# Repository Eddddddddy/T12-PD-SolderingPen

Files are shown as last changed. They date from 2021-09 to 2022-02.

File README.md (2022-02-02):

# T12-PD-SolderingPen

[Video introduction]<https://www.bilibili.com/video/BV1734y1D7u2>

使用atmega328p作为主控芯片，128x64 OLED屏幕，内置陀螺仪和蜂鸣器。能够读取控制部分电路温度和输入电压，主控电压，主控温度。具备自动启停的功能。

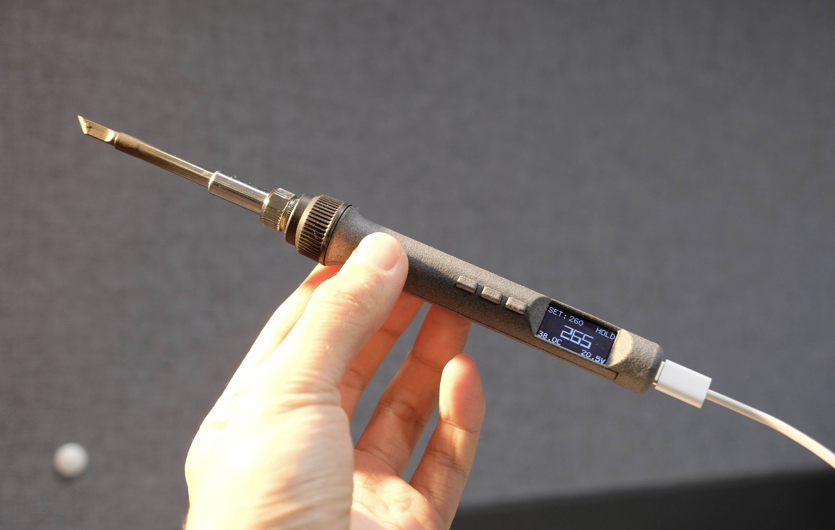
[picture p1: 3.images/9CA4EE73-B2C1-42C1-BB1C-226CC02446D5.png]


可以保存多组不同的烙铁头信息。烙铁主控部分代码基于<https://github.com/wagiminator/ATmega-Soldering-Station>.在屏幕驱动、按键驱动、休眠检测、陀螺仪和内部温度检测等方面做出调整与改进。

- 休眠功能通过陀螺仪进行检测，可以设置休眠时间和灵敏度。默认的阈值较灵敏，轻微的晃动就会唤醒。休眠功能可以关闭，将灵敏度的阈值设置为0即可。
- 蜂鸣器可以选择开启或关闭
- 加热方式可以选择直接加热或PID调节，但PID参数尚未调整，可在源代码中自行调整。
- 烙铁温度可以在设置中校准

## 制作信息

- 手柄部分请使用1.6mm双层板打样，主控部分请使用0.8mm四层板。

- 屏幕较为特殊，为0.96寸64x128分辨率sh1107驱动OLED屏幕，0.3mm脚距插接13pin接口。

- FS312协议芯片请使用H版，以支持20v电压。

- 建议开一张钢片用锡膏焊接，大大降低难度。

- 焊接完成之后需要飞线到预留的焊盘，进行程序烧录。

## 注意事项

- 支架与主控需共地
- 如果主控不是原厂的芯片，在information页面的主控温度可能会不正常。但不影响使用
- 建议通过<https://github.com/carlosefr/atmega>页面的步骤对芯片进行烧写。该开发板包将会释放BootLoader占用的flash空间，在下述“烧录引导程序”步骤中将熔丝位修改正确。
- 简单来说，安装上面连接中的开发板到Arduino IDE，并在开发板中选中"ATmega328/328p" - "ATmega328p" - "16 MHz" - 编程器："Arduino as ISP"
- 准备一个Arduino UNO，烧写Arduino示例程序中的ArduinoISP。将Arduino UNO的相应管脚与主控板上相应的飞线焊盘连接。在Arduino IDE中点击“烧录引导程序”，完成之后再点击“使用编程器上传”，即可完成烧录工作。

更多信息稍后更新。

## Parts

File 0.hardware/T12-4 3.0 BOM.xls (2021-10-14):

Comment | Description | Designator | Footprint | Quantity
100nF 10% 50V | 贴片电容 | C1, C3, C10, C17, C18 | 0603_C | 5
1uF 10% 50V | 贴片电容 | C2, C11, C13 | 0603_C | 3
2.2nF 10% 50V | 贴片电容 | C5 | 0603_C | 1
10uF 10% 50V | 贴片电容 | C6, C15, C16, C20 | 0603_C | 4
4.7uF 10% 50V | 贴片电容 | C7, C19 | 0603_C | 2
33pF 5% 50V | 贴片电容 | C9 | 0603_C | 1
10pF 5% 50V | 贴片电容 | C14 | 0603_C | 1
B5819W SL | 肖特基二极管 | D1, D3, D4 | SOD-123 | 3
1N4148WS T4 | 二极管 | D2 | SOD-323 | 1
22uh | 电感 | H1 | NR3015 | 1
OPA333AIDCKR |  | Designator47 | SC70-5 | 1
FXMAR2102UMX |  | Designator48 | UMLP-8 | 1
47uh |  | H2 | NR3015 | 1
TYPE-C-31-M-12 | USB Connectors 24 Receptacle 1 8.94*7.3mm RoHS | J | TYPE-C-31-M-12 | 1
AO4485 | Transistor: P-MOSFET; unipolar; -40V; -8A; 1.1W; SO8 | Q1 | SOIC127P600X175-8N | 1
SS8050 Y1 | 三极管 | Q2 | SOT-23(SOT-23-3) | 1
10KΩ ±1% | 贴片电阻 | R1, R6, R11, R12, R14, R15, R16 | 0603_R | 7
200KΩ ±1% | 贴片电阻 | R4 | 0603_R | 1
1KΩ ±1% | 贴片电阻 | R5 | 0603_R | 1
23.7KΩ ±1% | 贴片电阻 | R7 | 0603_R | 1
124KΩ ±1% | 贴片电阻 | R8 | 0603_R | 1
22KΩ ±1% | 贴片电阻 | R9 | 0603_R | 1
47KΩ ±1% | 贴片电阻 | R10 | 0603_R | 1
180KΩ ±1% | 贴片电阻 | R13 | 0603_R | 1
4.7KΩ ±1% | 贴片电阻 | R17, R18, R21, R22, R25, R27 | 0603_R | 6
100KΩ ±1% | 贴片电阻 | R23 | 0603_R | 1
560KΩ ±1% | 贴片电阻 | R26, R24 | 0603_R | 1
MP2451DT-LF-Z |  | U1 | SOT-23-6_L2.9-W1.6-P0.95-LS2.8-BR | 1
FS312 |  | U4 | FS312 | 1
LIS2DW12TR | Mems Digital Output Motion Sensor | U5 | LGA12R50P4X4_200X200X70 | 1
MCU-ATMEGA328P-AU(TQFP32) | 310010049 | U6 | TQFP32-0.8-7X7MM | 1
PMIC-LDO-XC6206P332MR-G(SOT23) | 310030099 | U7 | SOT-23 | 1
SH1107 |  | U8 | FH35C-13S | 1
TPS61040DBVRG4 | DC-DC芯片 | U9 | SOT-23-5 | 1
CSTCE16M0V51Z-R0 | 16MHz Ceramic Resonator Built in Capacitor 15pF +/- 0.2% -40C - 125C Surface Mount | Y1 | OSC_CSTCE16M0V51Z-R0 | 1
DET402 | 蜂鸣器 |  | SMD402
2*4*3.5MM 侧贴 | 贴片开关
1N4148 | 二极管 |  | SOD-523
S8050 J3Y | 三极管 |  | SOT-23
10KΩ ±1% | 贴片电阻 |  | 0603_R

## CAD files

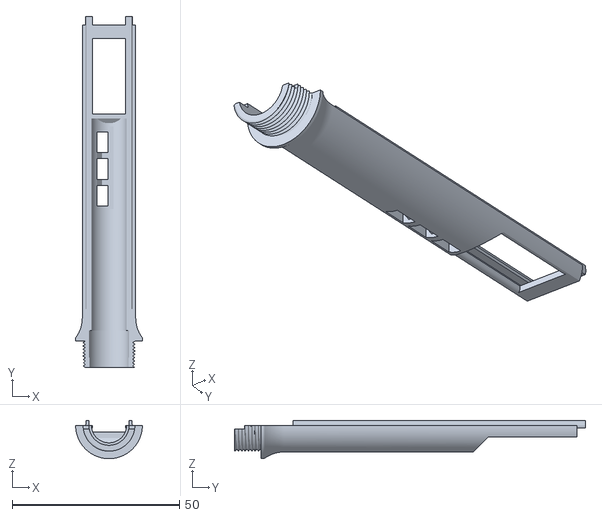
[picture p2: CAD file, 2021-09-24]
2.3D STL/part1.STL
20.0 x 105.0 x 11.5

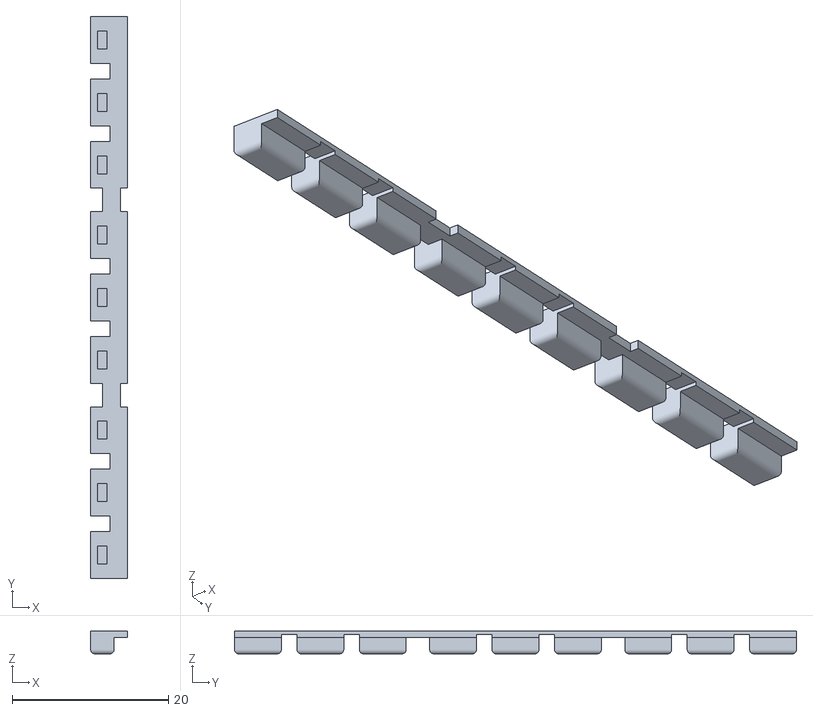
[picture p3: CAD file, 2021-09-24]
2.3D STL/buttons.STL
4.70 x 72.0 x 2.92

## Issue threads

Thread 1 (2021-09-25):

关于动画...

Challenger-0, 2021-09-25:
B站来的
您的项目应该是用Arduino开发的，用u8g2实现显示的吧
虽然我并不专业，但自认为有信心和能力帮您完成动画的部分
QQ1677712032

Eddddddddy, 2021-09-25:
来了！

hqs1, 2021-09-29:
LVGL yyds,但是328P的资源有点小，可能上ESP32这种主控比较舒服点

Eddddddddy, 2021-09-29:
> LVGL yyds,但是328P的资源有点小，可能上ESP32这种主控比较舒服点

对，我是真的后悔用328p，资源太少了，还得单独给一个供电

Closed 2021-10-03.

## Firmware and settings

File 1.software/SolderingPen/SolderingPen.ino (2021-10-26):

// SolderingPen
//
// ATmega328-controlled Soldering Pen for Hakko T12 Tips.
//
// This version of the code implements:
// - Temperature measurement of the tip
// - Direct or PID control of the heater
// - Temperature control via buttons
// - Boost mode by short pressing first button
// - Setup menu by long pressing first button
// - Handle movement detection by gyroscope
// - Iron unconnected detection (by idenfying invalid temperature readings)
// - Time driven sleep/power off mode if iron is unused (movement detection)
// - Measurement of input voltage, Vcc and ATmega's internal temperature
// - Information display on OLED
// - Buzzer
// - Calibrating and managing different soldering tips
// - Storing user settings into the EEPROM
// - Tip change detection
// - Can be used with either N or P channel mosfets
//
// Power supply should be in the range of 6V to 20V. PD, QC and other
// rapid-charging protocols.
//
// For calibration you need a soldering iron tips thermometer. For best results
// wait at least three minutes after switching on the soldering station before
// you start the calibration process.
//
// Controller:  ATmega328p
// Core:        Barebones ATmega (https://github.com/carlosefr/atmega)
// Clockspeed:  16 MHz external
//
// It is recommended not to use a bootloader!
//
// Thank you for the code contributions:
// - John Glavinos, https://youtu.be/4YDcWfOQmz4
// - createskyblue, https://github.com/createskyblue
// - TaaraLabs, https://github.com/TaaraLabs
// - wagiminator, https://github.com/wagiminator



// Libraries
#include <U8g2lib.h>             // https://github.com/olikraus/u8g2

#ifdef U8X8_HAVE_HW_SPI
#include <SPI.h>
#endif
#ifdef U8X8_HAVE_HW_I2C
#include <Wire.h>
#endif

#include <PID_v1.h>             // https://github.com/wagiminator/ATmega-Soldering-Station/blob/master/software/libraries/Arduino-PID-Library.zip
// (old cpp version of https://github.com/mblythe86/C-PID-Library/tree/master/PID_v1)
#include <EEPROM.h>             // for storing user settings into EEPROM
#include <avr/sleep.h>          // for sleeping during ADC sampling

#include "LIS2DW12Sensor.h"

// Firmware version
#define VERSION       "v1.5"

// Type of MOSFET
#define P_MOSFET                // P_MOSFET or N_MOSFET

// Type of OLED Controller
#define SH1107                 // SH1107
typedef u8g2_uint_t u8g_uint_t;

// Type of rotary encoder
#define ROTARY_TYPE   0         // 0: 2 increments/step; 1: 4 increments/step (default)
#define BUTTON_DELAY  5

// Pins
#define SENSOR_PIN    A0        // tip temperature sense
#define VIN_PIN       A1        // input voltage sense
#define BUZZER_PIN     5        // buzzer
#define BUTTON_PIN     6        // rotary encoder switch
#define BUTTON_P_PIN   7        // rotary encoder 1
#define BUTTON_N_PIN   8        // rotary encoder 2
#define CONTROL_PIN    9        // heater MOSFET PWM control
#define SWITCH_PIN    10        // handle vibration switch

// Default temperature control values (recommended soldering temperature: 300-380°C)
#define TEMP_MIN      150       // min selectable temperature
#define TEMP_MAX      400       // max selectable temperature
#define TEMP_DEFAULT  320       // default start setpoint
#define TEMP_SLEEP    150       // temperature in sleep mode
#define TEMP_BOOST     50       // temperature increase in boost mode
#define TEMP_STEP      10       // rotary encoder temp change steps

// Default tip temperature calibration values
#define TEMP200       216       // temperature at ADC = 200
#define TEMP280       308       // temperature at ADC = 280
#define TEMP360       390       // temperature at ADC = 360
#define TEMPCHP       30        // chip temperature while calibration
#define TIPMAX        8         // max number of tips
#define TIPNAMELENGTH 6         // max length of tip names (including termination)
#define TIPNAME       "BC1.5"   // default tip name

// Default timer values (0 = disabled)
#define TIME2SLEEP    30        // time to enter sleep mode in minutes
#define TIME2OFF       5        // time to shut off heater in minutes
#define TIMEOFBOOST   40        // time to stay in boost mode in seconds
#define LISTHRESHOLD  15        // LIS sensor threshold

// Control values
#define TIME2SETTLE   950       // time in microseconds to allow OpAmp output to settle
#define SMOOTHIE      0.05      // OpAmp output smooth factor (1=no smoothing; 0.05 default)
#define PID_ENABLE    false     // enable PID control
#define BEEP_ENABLE   true      // enable/disable buzzer
#define MAINSCREEN    1         // type of main screen (0: big numbers; 1: more infos)

// EEPROM identifier
#define EEPROM_IDENT  0xE76C   // to identify if EEPROM was written by this program

// MOSFET control definitions
#if defined (P_MOSFET)         // P-Channel MOSFET
#define HEATER_ON   255
#define HEATER_OFF  0
#define HEATER_PWM  255 - Output
#elif defined (N_MOSFET)       // N-Channel MOSFET
#define HEATER_ON   0
#define HEATER_OFF  255
#define HEATER_PWM  Output
#else
#error Wrong MOSFET type!
#endif

// Define the aggressive and conservative PID tuning parameters
double aggKp = 11, aggKi = 0.5, aggKd = 1;
double consKp = 11, consKi = 3, consKd = 5;

// Default values that can be changed by the user and stored in the EEPROM
uint16_t  DefaultTemp   = TEMP_DEFAULT;
uint16_t  SleepTemp     = TEMP_SLEEP;
uint8_t   BoostTemp     = TEMP_BOOST;
uint8_t   time2sleep    = TIME2SLEEP;
uint8_t   time2off      = TIME2OFF;
uint8_t   timeOfBoost   = TIMEOFBOOST;
uint8_t   MainScrType   = MAINSCREEN;
bool      PIDenable     = PID_ENABLE;
bool      beepEnable    = BEEP_ENABLE;
uint8_t   LISthreshold  = LISTHRESHOLD;

// Default values for tips
uint16_t  CalTemp[TIPMAX][4] = {TEMP200, TEMP280, TEMP360, TEMPCHP};
char      TipName[TIPMAX][TIPNAMELENGTH] = {TIPNAME};
uint8_t   CurrentTip   = 0;
uint8_t   NumberOfTips = 1;

// Menu items
const char *SetupItems[]       = { "Setup Menu", "Tip Settings", "Temp Settings",
                                   "Timer Settings", "Control Type", "Main Screen",
                                   "Buzzer", "Information", "Return"
                                 };
const char *TipItems[]         = { "Tip:", "Change Tip", "Calibrate Tip",
                                   "Rename Tip", "Delete Tip", "Add new Tip", "Return"
                                 };
const char *TempItems[]        = { "Temp Settings", "Default Temp", "Sleep Temp",
                                   "Boost Temp", "Return"
                                 };
const char *TimerItems[]       = { "Timer Settings", "Sleep Timer", "Off Timer",
                                   "Boost Timer", "IMU Threshold", "Return"
                                 };
const char *ControlTypeItems[]  = { "Control Type", "Direct", "PID" };
const char *MainScreenItems[]   = { "Main Screen", "Big Numbers", "More Infos" };
const char *StoreItems[]        = { "Store Settings ?", "No", "Yes" };
const char *SureItems[]         = { "Are you sure ?", "No", "Yes" };
const char *BuzzerItems[]       = { "Buzzer", "Disable", "Enable" };
const char *DefaultTempItems[]  = { "Default Temp", "deg C" };
const char *SleepTempItems[]    = { "Sleep Temp", "deg C" };
const char *BoostTempItems[]    = { "Boost Temp", "deg C" };
const char *SleepTimerItems[]   = { "Sleep Timer", "Seconds" };
const char *LISthresholdItems[] = { "IMU Threshold", "mg" };
const char *OffTimerItems[]     = { "Off Timer", "Minutes" };
const char *BoostTimerItems[]   = { "Boost Timer", "Seconds" };
const char *DeleteMessage[]     = { "Warning", "You cannot", "delete your", "last tip!" };
const char *MaxTipMessage[]     = { "Warning", "You reached", "maximum number", "of tips!" };

// Variables for pin change interrupt
volatile uint8_t  a0, b0, c0, d0;
volatile bool     ab0;
volatile int      count, countMin, countMax, countStep;
volatile bool     handleMoved;

// Variables for temperature control
uint16_t  SetTemp, ShowTemp, gap, Step;
double    Input, Output, Setpoint, RawTemp, CurrentTemp, ChipTemp;

// Variables for voltage readings
uint16_t  Vcc, Vin;

// State variables
bool      inSleepMode = false;
bool      inOffMode   = false;
bool      inBoostMode = false;
bool      inCalibMode = false;
bool      isWorky     = true;
bool      beepIfWorky = true;
bool      TipIsPresent = true;

// Timing variables
uint32_t  sleepmillis;
uint32_t  boostmillis;
uint32_t  buttonmillis;
uint8_t   goneMinutes;
uint8_t   goneSeconds;
uint8_t   SensorCounter = 255;

// Specify variable pointers and initial PID tuning parameters
PID ctrl(&Input, &Output, &Setpoint, aggKp, aggKi, aggKd, REVERSE);

// Setup u8g object depending on OLED controller
#if defined (SSD1306)
U8GLIB_SSD1306_128X64 u8g(U8G_I2C_OPT_DEV_0 | U8G_I2C_OPT_NO_ACK | U8G_I2C_OPT_FAST);
#elif defined (SH1106)
U8GLIB_SH1106_128X64 u8g(U8G_I2C_OPT_FAST | U8G_I2C_OPT_NO_ACK);
#elif defined (SH1107)
U8G2_SH1107_64X128_1_HW_I2C u8g(U8G2_R1, A3);
#else
#error Wrong OLED controller type!
#endif

// Buffer for drawStr
char F_Buffer[20];

// LIS2DW12Sensor
LIS2DW12Sensor Accelero(&Wire, LIS2DW12_I2C_ADD_L);
LIS2DW12_Event_Status_t state;
float lastLISTmp = 0;
float newLISTmp = 0;
uint8_t LISTmpTime = 0;


void setup() {
  // set the pin modes
  pinMode(SENSOR_PIN,   INPUT);
  pinMode(VIN_PIN,      INPUT);
  pinMode(BUZZER_PIN,   OUTPUT);
  pinMode(CONTROL_PIN,  OUTPUT);
  pinMode(BUTTON_P_PIN, INPUT_PULLUP);
  pinMode(BUTTON_N_PIN, INPUT_PULLUP);
  pinMode(BUTTON_PIN,   INPUT_PULLUP);
  pinMode(SWITCH_PIN,   INPUT_PULLUP);

  analogWrite(CONTROL_PIN, HEATER_OFF); // this shuts off the heater
  digitalWrite(BUZZER_PIN, LOW);        // must be LOW when buzzer not in use

  // setup ADC
  ADCSRA |= bit (ADPS0) | bit (ADPS1) | bit (ADPS2);  // set ADC prescaler to 128
  ADCSRA |= bit (ADIE);                 // enable ADC interrupt
  interrupts ();                        // enable global interrupts

  // // setup pin change interrupt for rotary encoder
  // PCMSK0 = bit (PCINT0);                // Configure pin change interrupt on Pin8
  // PCICR  = bit (PCIE0);                 // Enable pin change interrupt
  // PCIFR  = bit (PCIF0);                 // Clear interrupt flag

  // setup LIS
  Wire.begin();
  Accelero.begin();
  Accelero.Enable_X();
  Accelero.WriteReg(LIS2DW12_CTRL6, 0x04);
  Accelero.WriteReg(LIS2DW12_CTRL1, 0x17);
  Accelero.Set_FIFO_Mode(LIS2DW12_STREAM_MODE);

  // prepare and start OLED
  u8g.begin();
  //  if      ( u8g.getMode() == U8G_MODE_R3G3B2 )   u8g.setColorIndex(255);
  //  else if ( u8g.getMode() == U8G_MODE_GRAY2BIT ) u8g.setColorIndex(3);
  //  else if ( u8g.getMode() == U8G_MODE_BW )       u8g.setColorIndex(1);
  //  else if ( u8g.getMode() == U8G_MODE_HICOLOR )  u8g.setHiColorByRGB(255,255,255);

  // get default values from EEPROM
  getEEPROM();

  // read supply voltages in mV
  delay(100);
  Vcc = getVCC(); Vin = getVIN();

  // read and set current iron temperature
  SetTemp  = DefaultTemp;
  RawTemp  = denoiseAnalog(SENSOR_PIN);
  ChipTemp = getChipTemp();
  calculateTemp();

  // turn on heater if iron temperature is well below setpoint
  if ((CurrentTemp + 20) < DefaultTemp) analogWrite(CONTROL_PIN, HEATER_ON);

  // set PID output range and start the PID
  ctrl.SetOutputLimits(0, 255);
  ctrl.SetMode(AUTOMATIC);

  // set initial rotary encoder values
  //a0 = PINB & 1; b0 = PIND >> 7 & 1; ab0 = (a0 == b0);
  a0 = 0;
  b0 = 0;
  setRotary(TEMP_MIN, TEMP_MAX, TEMP_STEP, DefaultTemp);

  // reset sleep timer
  sleepmillis = millis();

  lastLISTmp = getLISTemp();

  // long beep for setup completion
  beep(); beep();
}


void loop() {
  ROTARYCheck();      // check rotary encoder (temp/boost setting, enter setup menu)
  SLEEPCheck();       // check and activate/deactivate sleep modes
  SENSORCheck();      // reads temperature and vibration switch of the iron
  Thermostat();       // heater control
  MainScreen();       // updates the main page on the OLED
}




// check rotary encoder; set temperature, toggle boost mode, enter setup menu accordingly
void ROTARYCheck() {
  // set working temperature according to rotary encoder value
  SetTemp = getRotary();

  // check rotary encoder switch
  uint8_t c = digitalRead(BUTTON_PIN);
  if ( !c && c0 ) {
    beep();
    buttonmillis = millis();
    while ( (!digitalRead(BUTTON_PIN)) && ((millis() - buttonmillis) < 500) );
    if ((millis() - buttonmillis) >= 500) SetupScreen();
    else {
      inBoostMode = !inBoostMode;
      if (inBoostMode) boostmillis = millis();
      handleMoved = true;
    }
  }
  c0 = c;

  // check timer when in boost mode
  if (inBoostMode && timeOfBoost) {
    goneSeconds = (millis() - boostmillis) / 1000;
    if (goneSeconds >= timeOfBoost) {
      inBoostMode = false;              // stop boost mode
      beep();                           // beep if boost mode is over
      beepIfWorky = true;               // beep again when working temperature is reached
    }
  }
}


// check and activate/deactivate sleep modes
void SLEEPCheck() {
  if (handleMoved) {                    // if handle was moved
    if (inSleepMode) {                  // in sleep or off mode?
      if ((CurrentTemp + 20) < SetTemp) // if temp is well below setpoint
        analogWrite(CONTROL_PIN, HEATER_ON);    // then start the heater right now
      beep();                           // beep on wake-up
      beepIfWorky = true;               // beep again when working temperature is reached
    }
    handleMoved = false;                // reset handleMoved flag
    inSleepMode = false;                // reset sleep flag
    inOffMode   = false;                // reset off flag
    sleepmillis = millis();             // reset sleep timer
  }

  // check time passed since the handle was moved
  goneSeconds = (millis() - sleepmillis) / 1000;
  if ( (!inSleepMode) && (time2sleep > 0) && (goneSeconds >= time2sleep) ) {
    inSleepMode = true;
    beep();
  }
  if ( (!inOffMode)   && (time2off   > 0) && ((goneSeconds / 60) >= time2off  ) ) {
    inOffMode   = true;
    beep();
  }
}


// reads temperature, vibration switch and supply voltages
void SENSORCheck() {
  uint16_t sampleNum = 0;
  Accelero.Get_FIFO_Num_Samples(&sampleNum);
  if (sampleNum == 32) {
    int16_t accelerometer[3][32];
    for (int i = 0; i < 32; i++) {
      int32_t accelerometer_temp[3];
      Accelero.Get_X_Axes(accelerometer_temp);
      accelerometer[0][i] = accelerometer_temp[0];
      accelerometer[1][i] = accelerometer_temp[1];
      accelerometer[2][i] = accelerometer_temp[2];
    }
    if (variance(accelerometer[0]) > LISthreshold) {
      handleMoved = true;
    } else if (variance(accelerometer[1]) > LISthreshold) {
      handleMoved = true;
    } else if (variance(accelerometer[2]) > LISthreshold) {
      handleMoved = true;
    }
  }
  analogWrite(CONTROL_PIN, HEATER_OFF);       // shut off heater in order to measure temperature
  delayMicroseconds(TIME2SETTLE);             // wait for voltage to settle

  double temp = denoiseAnalog(SENSOR_PIN);    // read ADC value for temperature

  if (! SensorCounter--) Vin = getVIN();      // get Vin every now and then

  analogWrite(CONTROL_PIN, HEATER_PWM);       // turn on again heater

  RawTemp += (temp - RawTemp) * SMOOTHIE;     // stabilize ADC temperature reading
  calculateTemp();                            // calculate real temperature value

  // stabilize displayed temperature when around setpoint
  if ((ShowTemp != Setpoint) || (abs(ShowTemp - CurrentTemp) > 5)) ShowTemp = CurrentTemp;
  if (abs(ShowTemp - Setpoint) <= 1) ShowTemp = Setpoint;

  // set state variable if temperature is in working range; beep if working temperature was just reached
  gap = abs(SetTemp - CurrentTemp);
  if (gap < 5) {
    if (!isWorky && beepIfWorky) beep();
    isWorky = true;
    beepIfWorky = false;
  }
  else isWorky = false;

  // checks if tip is present or currently inserted
  if (ShowTemp > 500) TipIsPresent = false;   // tip removed ?
  if (!TipIsPresent && (ShowTemp < 500)) {    // new tip inserted ?
    analogWrite(CONTROL_PIN, HEATER_OFF);     // shut off heater
    beep();                                   // beep for info
    TipIsPresent = true;                      // tip is present now
    ChangeTipScreen();                        // show tip selection screen
    updateEEPROM();                           // update setting in EEPROM
    handleMoved = true;                       // reset all timers
    RawTemp  = denoiseAnalog(SENSOR_PIN);     // restart temp smooth algorithm
    c0 = LOW;                                 // switch must be released
    setRotary(TEMP_MIN, TEMP_MAX, TEMP_STEP, SetTemp);  // reset rotary encoder
  }
}


// calculates real temperature value according to ADC reading and calibration values
void calculateTemp() {
  if      (RawTemp < 200) CurrentTemp = map (RawTemp,   0, 200,                     21, CalTemp[CurrentTip][0]);
  else if (RawTemp < 280) CurrentTemp = map (RawTemp, 200, 280, CalTemp[CurrentTip][0], CalTemp[CurrentTip][1]);
  else                    CurrentTemp = map (RawTemp, 280, 360, CalTemp[CurrentTip][1], CalTemp[CurrentTip][2]);
}


// controls the heater
void Thermostat() {
  // define Setpoint acoording to current working mode
  if      (inOffMode)   Setpoint = 0;
  else if (inSleepMode) Setpoint = SleepTemp;
  else if (inBoostMode) Setpoint = SetTemp + BoostTemp;
  else                  Setpoint = SetTemp;

  // control the heater (PID or direct)
  gap = abs(Setpoint - CurrentTemp);
  if (PIDenable) {
    Input = CurrentTemp;
    if (gap < 30) ctrl.SetTunings(consKp, consKi, consKd);
    else ctrl.SetTunings(aggKp, aggKi, aggKd);
    ctrl.Compute();
  } else {
    // turn on heater if current temperature is below setpoint
    if ((CurrentTemp + 0.5) < Setpoint) Output = 0; else Output = 255;
  }
  analogWrite(CONTROL_PIN, HEATER_PWM);     // set heater PWM
}


// creates a short beep on the buzzer
void beep() {
  if (beepEnable) {
    for (uint8_t i = 0; i < 255; i++) {
      digitalWrite(BUZZER_PIN, HIGH);
      delayMicroseconds(125);
      digitalWrite(BUZZER_PIN, LOW);
      delayMicroseconds(125);
    }
  }
}


// sets start values for rotary encoder
void setRotary(int rmin, int rmax, int rstep, int rvalue) {
  countMin  = rmin << ROTARY_TYPE;
  countMax  = rmax << ROTARY_TYPE;
  countStep = rstep;
  count     = rvalue << ROTARY_TYPE;
}


// reads current rotary encoder value
int getRotary() {
  Button_loop();
  return (count >> ROTARY_TYPE);
}


// reads user settings from EEPROM; if EEPROM values are invalid, write defaults
void getEEPROM() {
  uint16_t identifier = (EEPROM.read(0) << 8) | EEPROM.read(1);
  if (identifier == EEPROM_IDENT) {
    DefaultTemp = (EEPROM.read(2) << 8) | EEPROM.read(3);
    SleepTemp   = (EEPROM.read(4) << 8) | EEPROM.read(5);
    BoostTemp   =  EEPROM.read(6);
    time2sleep  =  EEPROM.read(7);
    time2off    =  EEPROM.read(8);
    timeOfBoost =  EEPROM.read(9);
    MainScrType =  EEPROM.read(10);
    PIDenable   =  EEPROM.read(11);
    beepEnable  =  EEPROM.read(12);
    CurrentTip  =  EEPROM.read(13);
    NumberOfTips = EEPROM.read(14);
    LISthreshold = EEPROM.read(15);


    uint8_t i, j;
    uint16_t counter = 16;
    for (i = 0; i < NumberOfTips; i++) {
      for (j = 0; j < TIPNAMELENGTH; j++) {
        TipName[i][j] = EEPROM.read(counter++);
      }
      for (j = 0; j < 4; j++) {
        CalTemp[i][j]  = EEPROM.read(counter++) << 8;
        CalTemp[i][j] |= EEPROM.read(counter++);
      }
    }
  }
  else {
    EEPROM.update(0, EEPROM_IDENT >> 8); EEPROM.update(1, EEPROM_IDENT & 0xFF);
    updateEEPROM();
  }
}


// writes user settings to EEPROM using updade function to minimize write cycles
void updateEEPROM() {
  EEPROM.update( 2, DefaultTemp >> 8);
  EEPROM.update( 3, DefaultTemp & 0xFF);
  EEPROM.update( 4, SleepTemp >> 8);
  EEPROM.update( 5, SleepTemp & 0xFF);
  EEPROM.update( 6, BoostTemp);
  EEPROM.update( 7, time2sleep);
  EEPROM.update( 8, time2off);
  EEPROM.update( 9, timeOfBoost);
  EEPROM.update(10, MainScrType);
  EEPROM.update(11, PIDenable);
  EEPROM.update(12, beepEnable);
  EEPROM.update(13, CurrentTip);
  EEPROM.update(14, NumberOfTips);
  EEPROM.update(15, LISthreshold);

  uint8_t i, j;
  uint16_t counter = 16;
  for (i = 0; i < NumberOfTips; i++) {
    for (j = 0; j < TIPNAMELENGTH; j++) EEPROM.update(counter++, TipName[i][j]);
    for (j = 0; j < 4; j++) {
      EEPROM.update(counter++, CalTemp[i][j] >> 8);
      EEPROM.update(counter++, CalTemp[i][j] & 0xFF);
    }
  }
}
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

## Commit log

2021-08-01 add T12 holder
    [支架1.PcbDoc, 支架2.PcbDoc]
2021-08-03 update folder structure
    [T12 holder part1.PcbDoc, T12 holder part2.PcbDoc]
2021-08-10 update PCB files
    add buzzer to holder PCB.
    add screen reset pin to MCU.
    add buzzer solder.
    [T12 holder part1.PcbDoc, T12 holder part2.PcbDoc]
2021-08-11 fix some error
    [T12 holder part1.PcbDoc, T12 holder part2.PcbDoc]
2021-08-21 Update SolderingPen.ino
    Change the method of sleep detection.
2021-09-24 Update SolderingPen.ino
    add reset pin of OLED
    update LIS temperature algorithm
2021-09-24 Update SolderingPen.ino
    fixed the error of VIN value on main screen
    [SolderingPen.ino]
2021-09-24 update hardware
    [T12 holder part2.PcbDoc, T12-4 3.0 SMT solder.PcbDoc, buttons.STL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]
2021-09-25 add BOM
    [T12-4 3.0 BOM.xls]
2021-09-25 Create T12 holder part3.PcbDoc
    [T12 holder part3.PcbDoc]
2021-09-25 Update T12-4 3.0 BOM.xls
    [T12-4 3.0 BOM.xls]
2021-10-05 Create T12.SchDoc
    upload SchDoc
    [T12.SchDoc]
2021-10-26 Add hex file and Fix LIS2DW12 temperature (maybe
    [SolderingPen.ino]
